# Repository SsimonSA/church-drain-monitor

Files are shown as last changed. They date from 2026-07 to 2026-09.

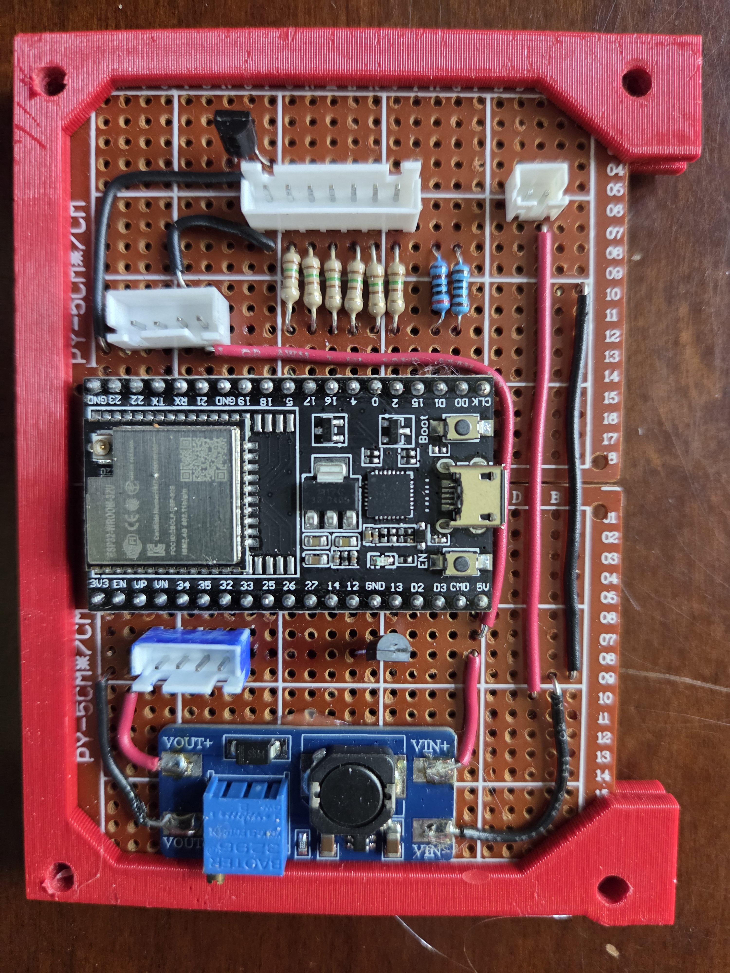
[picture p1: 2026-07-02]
firmware/photos/20-perfboard-component-side.jpg

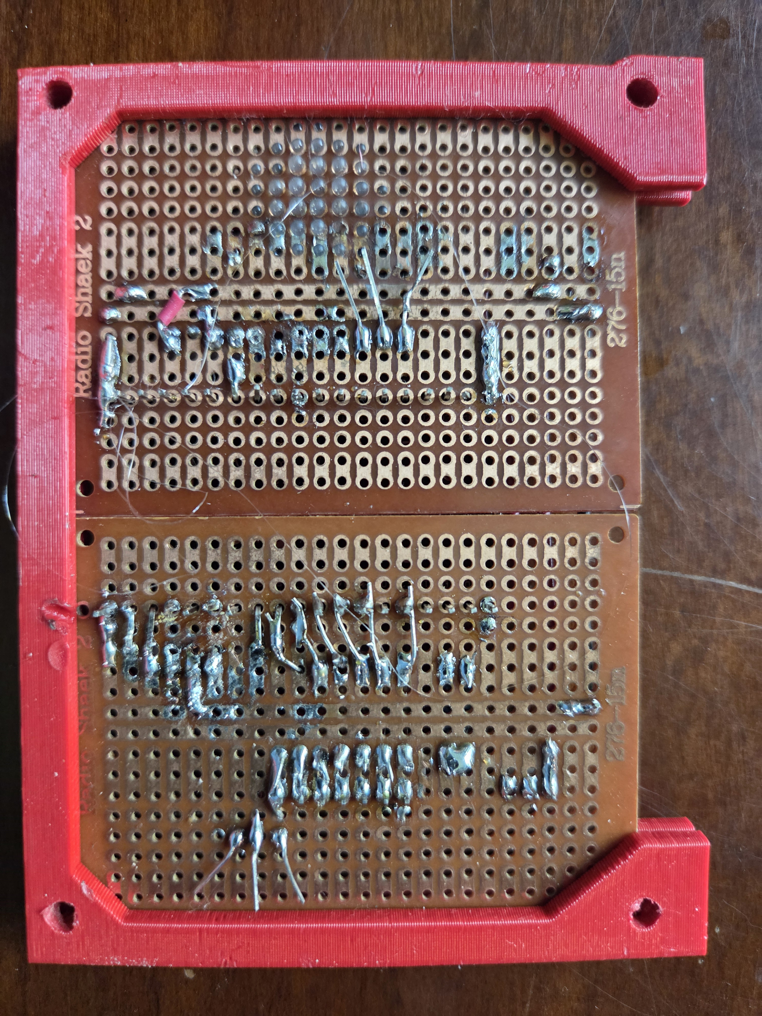
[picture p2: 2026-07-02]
firmware/photos/21-perfboard-solder-side.jpg

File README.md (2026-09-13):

# 🚰 Church Water Drain Monitor

An ESP32-based early-warning system for a church kitchen floor drain that backs up
under a wash sink. A float rides in a 2" PVC standpipe; an HC-SR04 ultrasonic sensor
reads the float height down the bore, driving a 5-LED level bar, a blinking overflow
lamp, and a piezo alarm — and posting depth telemetry to InfluxDB for a Grafana
dashboard. The box is a self-contained alarm first, a cloud sensor second.

See [PROJECT.md](PROJECT.md) for the full design history (sensing approaches tried,
mechanical build, calibration).

## Getting the data off the box

The site has no dependable WiFi, so the firmware assumes it is usually offline and
logs regardless:

- **Store and forward.** Readings go to a persistent log in flash (LittleFS, two
  rotating files, ~37,000 readings ≈ 12 h of continuous 1 Hz logging or ~8 months of
  calm heartbeats). It survives reboots, brownouts and power cuts. When a network
  appears, the backlog is uploaded oldest-first in bounded chunks and back-dated to
  when it was actually measured, so Grafana fills in the past with no dashboard
  changes.
- **Local download.** The device also serves its own history over plain HTTP on the
  LAN — park next to it, turn on a phone hotspot, and open
  **`http://drain.local/log.csv`** (or `http://<ip>/log.csv`; the IP is reported in
  telemetry as the `ip` field). This path needs no InfluxDB, no token, no retention
  window and no internet.

Readings are stamped with **uptime**, not wall-clock, so logging never depends on the
device having had a clock; absolute time is applied on the way out once NTP lands.
Readings taken during a boot that never reached NTP keep their shape in the CSV
(uptime column) but are deliberately **not** sent to InfluxDB — a guessed timestamp
would corrupt the dashboard. A battery-backed RTC (DS3231) would close that gap.

## Repository layout

| Path | What it is |
|---|---|
| `firmware/` | **Field firmware** (`StJoesDrainMonitor`) — the deployed build: sensor, LEDs, buzzer, button, InfluxDB telemetry. |
| `experiments/BenchTest/` | Interactive bench harness — exercise LEDs / buzzer / sensor / WiFi / InfluxDB write from a serial menu. |
| `experiments/BtnLedTest/` | Minimal button + LED sanity sketch. |
| `experiments/vl53l1x-abandoned/` | Abandoned VL53L1X ToF version (kept for reference). |
| `experiments/ultrasonic-original-2025/` | The very first sketch (bare HC-SR04, six LEDs), archived from the old sketchbook. |
| `hardware/3d-models/` | Copies of the printable parts (float, tube liner, sensor cap). |

## Setup — credentials

Credentials are **not** committed. Each firmware project reads them from a gitignored
`secrets.h`. To build:

```sh
cd firmware/src   # (and likewise experiments/BenchTest/src)
cp secrets.example.h secrets.h
# then edit secrets.h with your WiFi network(s) and InfluxDB write token
```

`secrets.h` provides `WIFI_NETS[]`, `N_WIFI`, and `INFLUX_TOKEN`. Use a **write-only,
bucket-scoped** InfluxDB token — that token is embedded in the compiled binary.

## Field visits

The unit is offline except when someone is standing next to it with a phone hotspot, so
an update and its first test happen on the same trip.
**[firmware/docs/field-visit-checklist.md](firmware/docs/field-visit-checklist.md)** is
the pre-flight for that: what to bring, what should happen, what to verify before
leaving, and how to read the serial log if it doesn't.

## Over-the-air updates

The field firmware self-updates over the internet — the device polls a manifest and
flashes a newer binary from a GitHub release when the water is low. There is no push
from the IDE. Full process and the publish/rollback steps are in
[firmware/ota/README.md](firmware/ota/README.md); the live manifest is
[firmware/ota/manifest.txt](firmware/ota/manifest.txt).

## Toolchain

PlatformIO (`espressif32` / `esp32dev`). Open a project folder and `pio run -t upload`.

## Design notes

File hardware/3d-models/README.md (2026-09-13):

# 3D models

Copies of the printable parts, taken from `Dropbox\3D Objects` in September 2026.
Edit the originals there in your slicer; refresh these copies when they change.

| File | Part |
|---|---|
| `Drain Float.3mf` | Float that rides inside the 2" PVC standpipe (2026-07-01) |
| `Drain Tube Liner.3mf` | Liner for the standpipe bore (2026-07-01) |
| `Dist Sensor Cap.3mf` | End cap holding the HC-SR04 at the top of the pipe (2026-06-02) |

The display enclosure and lid were also printed, but the matching files in
`3D Objects` are not named for this project (candidates: `Circuit Board Enclosure`,
`Enclosure Cover`, `Sensor Enclosure`, `Cap V2`). Copy them here once identified.

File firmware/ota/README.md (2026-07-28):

# OTA update process (pull-based)

The deployed firmware ([../src/StJoesDrainMonitor.ino](../src/StJoesDrainMonitor.ino))
updates itself. There is **no push from the IDE** — the device drives everything:

1. Every ~6 h (and ~1 min after boot), if the water level is low and WiFi is up, the
   device fetches [`manifest.txt`](manifest.txt) over HTTPS.
2. It compares the manifest's version to its compiled-in `FW_VERSION`.
3. If the manifest version is **greater**, it downloads the `.bin` at the URL in the
   manifest and flashes it, then reboots into the new image.
4. Equal or lower → no-op. (This is what prevents a reflash loop.)

`manifest.txt` is served straight off the `main` branch via
`raw.githubusercontent.com`, so editing it here **is** publishing.

## Manifest format

Exactly two lines, no JSON:

```
<version integer>
<https URL of the .bin>
```

## Publishing a new firmware version

Do these in order — **bin first, manifest last** — so a device can never fetch a
manifest that points at a `.bin` that isn't uploaded yet.

1. **Bump the version in the source.** Edit `const int FW_VERSION` in
   `../src/StJoesDrainMonitor.ino` to the new number (e.g. `2`).
2. **Build** the release binary:
   ```sh
   cd ..            # into firmware/
   pio run          # output: .pio/build/esp32dev/firmware.bin
   ```
3. **Cut a GitHub release** and attach the binary. The asset's download filename is the
   file's basename and the manifest URL must match it, so **rename the bin before upload**
   — the `path#label` form only sets a display *label*, NOT the download filename:
   ```sh
   cp .pio/build/esp32dev/firmware.bin StJoesDrainMonitor-v2.bin
   gh release create fw-v2 \
     --title "Firmware v2" --notes "what changed" \
     StJoesDrainMonitor-v2.bin
   ```
4. **Flip the manifest** — edit `manifest.txt` to:
   ```
   2
   https://github.com/SsimonSA/church-drain-monitor/releases/download/fw-v2/StJoesDrainMonitor-v2.bin
   ```
   then commit + push to `main`.

Within one check interval each device sees version 2 > its running 1, updates, and
reboots. Confirm success in Grafana: the `fw` field in the `depth` measurement flips
to `2`, and the unit keeps reporting. **To roll back**, point the manifest back at the
older release and its lower version number — but note a device already running the
newer build won't downgrade (its `FW_VERSION` is now higher), so a true rollback
usually means cutting a new release with a *higher* number containing the old code.

## Notes / limitations

- **The reading log lives in the `spiffs` partition, and OTA never touches it.** Only
  the app partition is rewritten, so a firmware update keeps the stored history. Two
  things do wipe it: a change to the partition table (don't), and a change to the
  on-flash record layout. The latter is guarded — `struct Reading` has a
  `static_assert` on its size and the log carries a `LOG_MAGIC` stamp, so a mismatched
  build wipes the log deliberately at boot instead of decoding old bytes as garbage
  depths. **If you change `struct Reading`, bump `LOG_MAGIC`.**
- **First boot of v5 formats that partition** (it was never used before), which adds a
  few seconds to that one boot.

- **Download integrity, not boot-rollback.** The ESP32 verifies the image (size +
  checksum) before switching the boot partition, so a corrupt/truncated *download*
  can't brick the device — the current firmware keeps running. It does **not** auto-
  revert a firmware that flashes cleanly but then crashes at runtime; the Arduino-ESP32
  bootloader isn't built with app-rollback enabled. Test each build on the bench before
  cutting a release.
- **Local post-update self-check (network-independent).** The firmware classifies each
  boot from `esp_reset_reason()` and an NVS crash counter, and logs it over serial:
  `first boot of fw vN`, `clean boot OK`, `CRASH (PANIC/WDT) bad-boot k/3 X`, or a loud
  `SUSPECT BUILD` after 3 firmware crashes. Because it's local, it flags a bad build
  even at a site with no WiFi — you don't have to infer health from dashboard silence.
  **Brownouts are called out separately** as a power fault and never count toward the
  suspect threshold (a flaky supply must not masquerade as a bad binary). The last reset
  reason is also sent as the `rst` telemetry field so Grafana can annotate reboots.
  This surfaces a bad build; it still can't *auto-revert* one (that needs the rollback
  bootloader) — a confirmed-bad unit needs a USB reflash.
- **Safe mode.** Hitting the same 3-crash threshold also disables the subsystems that
  aren't needed to warn anybody: the filesystem and the web server. The sensor, LED
  bar, overflow lamp and buzzer keep running, and telemetry falls back to the RAM
  buffer. It is not a rollback — the unit still needs a USB reflash — but a bad build
  degrades into a working drain alarm instead of a dead box, which matters because
  recovery requires physically visiting the site.
- **TLS is encrypt-only** (`setInsecure()`), matching the telemetry path. Fine for a
  public binary; if you later want MITM protection, pin GitHub's root CA or add a
  SHA-256 check to the manifest.
- **Power first.** Do not rely on OTA until the field unit has the ≥2 A supply + bulk
  cap — a brownout during the flash write is the one thing that *can* brick it.

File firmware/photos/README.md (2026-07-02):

# Project photos

Drop the St. Joes Drain Monitor photos here so future Claude Code sessions can view
them (Claude can open image files on disk with the Read tool, but cannot save images
that were pasted into a chat).

Suggested filenames (match the manifest in the project memory `drain-enclosure.md`):

- `01-enclosure-open.jpg`      — box open: perfboard/ESP32 + lid with 6 LED bezels
- `02-perfboard-closeup.jpg`   — ESP32-WROOM-32U, LED resistors, JST connectors
- `03-front-panel.jpg`         — DRAIN MONITOR / OVERFLOW WARNING + 5-LED level bar
- `04-sr04-in-cap.jpg`         — HC-SR04 in the round 3D-printed sensor cap
- `05-probe-assembly.jpg`      — PVC tube + sensor cap + pencil float + connector
- `06-sr04-cap-closeup.jpg`    — HC-SR04 cap close-up
- `07-esp32-breadboard.jpg`    — ESP32-WROOM-32D on breadboard
- `08-drain-site.jpg`          — the square floor sink / drain
- `09-drain-measured.jpg`      — tape measure across the drain opening (~10-11")
- `10-buzzer-amazon.png`       — the DC 3-24V 95dB active piezo buzzer listing

Any filenames are fine — these just keep them tidy and matched to the notes.

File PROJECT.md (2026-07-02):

# 🚰 Drain Overflow Monitor

Visual early-warning system for a church kitchen floor drain that occasionally backs up
under a wash sink. Goal: warn **before** overflow, in a wet/dirty/greasy environment.

## The problem

- Floor drain begins **overflowing at ~5.5"** of water depth.
- Environment is hostile to sensors: wet, dirty, soap, grease, food residue, scum.
- Need a visual warning that escalates as water rises, flashing before overflow.

### The drain site (photographed)

- Commercial **enameled cast-iron floor sink**, roughly **~12" square opening**, **5.5" deep**,
  with a **dome/flat strainer at the bottom**.
- It's an **indirect-waste receptor**: several vertical PVC pipes plus a horizontal one discharge
  *into* the basin. It backs up when inflow outruns the bottom drain, overflowing at 5.5"
  (flush with the floor).
- The basin is **crowded with existing pipes** — a float standpipe must tuck into a corner,
  rest on the bottom, and have intake holes low so it tracks the basin water level.

## Display (already built)

The enclosure is built and the LED layout is finalized:

- **5 level LEDs:** Green, Green, Yellow, Yellow, Red
- **1 large red LED** that flashes when overflow is imminent

| Water depth | Indication |
|---|---|
| 0" | 1st green LED |
| ~1"  | 2 LEDs |
| ~2"  | 3 LEDs |
| ~3"  | 4 LEDs |
| ~3.5"| 5 LEDs |
| 4" | Large red LED begins flashing |
| 5.5" | Actual overflow begins |

Only need to measure **0"–4"** before warning.

### As-built display unit (photographed)

- 3D-printed two-part enclosure, hex-textured lid: **"DRAIN MONITOR / OVERFLOW WARNING / WATER LEVEL"**, clamp-mounted.
- **ESP32-WROOM-32U** DevKit on a red-framed perfboard.
- 5 bar LEDs (G, G, Y, Y, R) wired through a row of current-limiting resistors; one large **panel-mount red overflow indicator** up top.
- **Toggle power switch** in the box; USB-powered.
- **JST connectors** for the detachable lid-LED harness and for the sensor cable; sensor cable uses an inline waterproof bullet connector.

Current firmware pin map (from the legacy `.ino` — **verify against actual wiring** before reuse):
LGLED=18, HGLED=5, LYLED=17, HYLED=16, LRLED=4, overflow LED=2. (The panel-mount overflow indicator may have a built-in resistor — only ~5 board resistors are visible, matching the 5 bar LEDs.)

## Sensing approach — history

1. **JSN-SR04T ultrasonic** — ❌ Beam spread too wide, drain-wall reflections, splashing, dirt. Unreliable.
2. **VL53L1X ToF (TOF400C modules)** — explored FOV, ROI reduction, Long mode, timing budgets,
   smoothing, auto-calibration. Better than ultrasonic but ❌ still untrustworthy: splashes,
   dirty/changing reflectivity, scum accumulation.
   - *`experiments/vl53l1x-abandoned/ChurchWaterDrainMonito.ino` is this abandoned VL53L1X version.*
3. **Float + Hall sensors** — keeps electronics dry, easy to clean, immune to splashes/optics.
   Designed but **set aside** (see "Alternative / fallback" below) in favor of #4.
4. **Float + HC-SR04 in a pipe (CURRENT direction)** — return to the HC-SR04, but fix its old
   failure modes *mechanically*: a float in a 2" PVC pipe gives the ultrasonic a clean, flat,
   consistent target, and the pipe bore acts as a waveguide that collimates the beam (no more
   drain-wall reflections or splashing). Plays to the SR04's strength at short range. 🔬 Under test.

## Current direction: float + HC-SR04 in a 2" PVC pipe

- **2" PVC pipe** stands vertically in the drain; an **HC-SR04 in a 3D-printed end cap** sits at
  the **top**, aimed down the bore.
- A **3D-printed float** rides on the water surface inside the pipe. The SR04 measures distance to
  the **flat top of the float** → water level = pipe geometry − measured distance.
- The pipe shields the float from splashing/turbulence and collimates the ultrasonic beam.

**Geometry (test rig):** pipe **12" long**, float **~1.5" long**. The float is *closest* to the
sensor at overflow and *farther* as water drops, so:
- At overflow (~5.5" water), sensor-to-float-top ≈ **5"** — comfortably outside the SR04 dead zone.
- The near dead zone (~2 cm, ring-down) is therefore **never reached** in this geometry. The bench
  sweep confirms accuracy/linearity/repeatability over the full travel rather than chasing a dead zone.

### Bench test rig (built, photographed)

- 2" PVC pipe + 3D-printed cap holding the HC-SR04 at one end, on a breadboard ESP32.
- The black float is **hot-glued to a pencil** as a manual actuator: push the float to a known
  position (read off a tape measure at the open end) and compare to the SR04 distance reading.
- Goal: characterize **known float position vs. measured distance** — accuracy, linearity,
  repeatability, and where the near dead zone begins.

## Alternative / fallback: float inside PVC pipe (Hall-sensor version)

- Vertical **1.5" Schedule 40 PVC** pipe; water enters through holes near the bottom.
- A **float** rides up/down inside the pipe with a **magnet** attached.
- **Analog Hall-effect sensors mounted outside the pipe** read the magnet's field.

### Sensors

- Purchased **10x DRV5055A1QLPG** — analog Hall-effect, output proportional to field strength,
  good for interpolation.
- Sensor count strategy evolved: 5 → 3 with interpolation. Current thinking: **3 sensors** may
  suffice for the 0"–4" range, e.g. Sensor 1 = 0", Sensor 2 = 2", Sensor 3 = 4". Magnet field
  overlaps adjacent sensors; interpolate all 3 analog values to estimate float position
  continuously, then map to the LED display.

### Float design

- **38 mm OD × 50 mm long**, pill-shaped, fits inside 1.5" PVC (ID ≈ 41 mm → ~1.5 mm clearance
  per side, tolerant of scum/buildup/print imperfection).
- **Bottom half:** rounded bottom, hollow chamber, magnet pocket.
- **Top half:** M32×2 threaded cap, domed top, tool slot.
- **Thread clearance:** female 32.3 mm / male 31.7 mm (0.6 mm total, 0.3 mm/side) — good FDM start.
- **Magnet:** 10 mm dia × 2.7 mm thick neodymium, in bottom of float, epoxy-sealed. Serves as
  Hall target **and** ballast (keeps float oriented).
- **Buoyancy:** hollow PLA float with a **Styrofoam insert** — stays buoyant even if PLA leaks,
  no perfect seal required.

## Audible alarm (new)

- Adding a **piezo buzzer**: WEICHUANG **SFM-27-W**, DC **3–24 V**, **90 dB**, *active* (self-oscillating,
  continuous tone — just apply DC, no PWM/tone needed). Arriving 2026-05-29.
- **Intended trigger: ~1" below overflow ≈ 4.5" water depth** — between the big-red-LED flashing
  onset (4") and actual overflow (5.5"). Final threshold deferred until the distance experiments
  are done.
- **Drive note:** an active buzzer rated to 24 V can draw more current than an ESP32 GPIO should
  source directly — plan to drive it through a transistor/MOSFET (or confirm draw at 3.3–5 V first).

## Status

**Mechanical:** ✅ enclosure built · ✅ LED layout finalized · ✅ magnet selected · ✅ Hall sensors
ordered · float design underway · threaded cap modeled · 1.5" PVC selected.

**Electronics:** ✅ ESP32 on hand · ✅ DRV5055 sensors purchased. Need: sensor mounting
arrangement, calibration strategy, final interpolation algorithm.

**Software (Hall version):** Not started. Need to: read 3 DRV5055 analog sensors → smooth →
calculate float position → convert to water depth → drive LEDs → flash overflow LED at 4".

## Next major milestone

Build the float, install it in a piece of 1.5" PVC, and **characterize magnetic field vs. height
using one DRV5055 sensor** before committing to final sensor spacing. That experiment determines
how many sensors are actually needed.

The **old ultrasonic test rig** (PVC tube + sensor in a printed end-cap + tape-measure position
reference + breadboard ESP32) is a ready template for this characterization: slide the
magnet/float along the pipe, log DRV5055 analog reading vs. tape-measure position.

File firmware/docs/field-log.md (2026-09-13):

# Field log

Running record of site visits and deployment state. Newest entry at the top.
Add an entry for every visit and every release, even if the outcome is unknown.

## 2026-09-13 — firmware v6 released (flush-before-NTP fix)

- flushChunk() now stops at the first record from the current boot while NTP is still
  pending, so a reboot no longer discards its own backlog from the InfluxDB path.
- Sensing, thresholds and the on-flash record format are unchanged; the stored log
  survives the update.
- Release fw-v6 published and the manifest flipped. Lands on the next visit: stay on the
  hotspot 10+ min, expect the OTA reboot within a minute or two, confirm fw=6 in Grafana.
- Also dropped the unjoinable `SJC Parish Guest` entry from `secrets.h` (5 GHz only) so
  the unit stops burning a 10 s timeout on it each scan cycle. Baked into the v6 binary.
- The readings from 09-01 to 09-13 are still only on the device. Pull `/log.csv` on the
  next visit before the OTA reboot if you want them.

## 2026-09-13 — hotspot drive-by, backlog stops at 09-01

- Hotspot on outside the kitchen. The unit connected and delivered its backlog, but only
  from Sun 08-30 11:45 through Tue 09-01 12:12 EDT (598 readings, hotspot IP 10.73.185.210,
  a different address from the 08-30 flush, so this was today's delivery). Nothing newer
  arrived, and no live readings from today either.
- One real event in that window: Tue 09-01 08:57:22 to 08:57:30, a 9-second excursion
  peaking at 4.82" (raw jumped, slew limiter ramped 1.5, 3.0, 4.5, 4.82, back down).
  Enough to trip the 4.5" fast chirp for a few seconds. Then the 1 Hz settle window and a
  return to calm 10-minute heartbeats until 12:12.
- **Diagnosis (from the firmware, not yet confirmed on the device):** the unit rebooted
  around 12:15 on 09-01 (today's rows carry rst=1, a clean power-on). The new boot had no
  NTP until today. On connect, flushChunk() runs before NTP lands, dates the old session's
  records via the saved anchor, but treats the new session's own pre-NTP records as
  undatable and advances the delivery cursor past them. Seconds later NTP arrives, too late.
  Twelve days of readings are still on flash and are now datable for `/log.csv`, but the
  InfluxDB path has skipped them for good.
- No live point from today because calm mode enqueues only every 10 min and the visit was
  shorter than that.
- **Next visit:** stay on the hotspot 10+ min, download `http://<ip>/log.csv` (the ip field
  shows the address), and read the serial boot line `LOG: mounted — session=N` to confirm
  the session count went up. Ask whether anyone unplugged the box around noon on 09-01.
- **v6 fix:** in flushChunk(), when g_bootEpoch is still 0, stop the chunk at the first
  record from the current session instead of skipping it, so the backlog waits for NTP.

## 2026-09-13 — status check (no visit)

- Reconstructed state from the repo on the desktop laptop. No record of the 2026-08-27
  visit had reached this machine because Claude session data does not sync via Dropbox.
- Added this log and a `CLAUDE.md` so outcomes are written into the repo from now on.
- Moved the project from `Dropbox\Arduino\ChurchWaterDrainMonito` to
  `Dropbox\Sparks Analytics\Projects\ChurchDrainMonitor`, folding in the 2025 sketch and
  the drain 3D models. A signpost README was left at the old path.
- Session history from the other laptop is now shared via Dropbox. The 08-27 through
  08-30 entries below were reconstructed from it.

## 2026-08-30 — hotspot drive-by, backfill confirmed

- Turned on the phone hotspot outside the kitchen. The unit flushed 358 readings covering
  Fri 08-28 00:00 to Sun 08-30 11:35 EDT at exactly 6 per hour, zero gaps.
- Health: fw=5, reset reasons only sw-restart (the OTA) and power-on, no brownout, no panic.
  21 of 21 pings kept on every reading, distance stable within 0.3 cm. Bin dry.
- Established that `SJC Parish Guest` is 5 GHz only. The ESP32 can never join it, so the
  unit is a walk-up logger with no remote alerting until a 2.4 GHz SSID exists.
- Buffer headroom is about 132 days at the calm cadence, so visits are not time-pressured.
- **Open:** ask the parish to enable 2.4 GHz on the AP; drop the dead guest SSID from
  `secrets.h` on the next reflash; rotate the InfluxDB write token; verify depth accuracy
  in the real drain at known fill levels.

## 2026-08-28 — morning after

- The last near-overflow tests from the evening were missing in Grafana. Two causes found:
  the unit was on laptop USB, which browns out the radio while readings keep landing on
  flash, and it was rebooted several times. The firmware keeps only one NTP session anchor,
  so readings from a boot that never reached NTP can never be dated and are skipped on the
  InfluxDB path. They remain in `/log.csv` with the uptime column filled.
- Not a device fault. The single-session anchor is a candidate fix for v6.

## 2026-08-27 — site visit, first v5 install (done)

- On site with the phone hotspot from about 17:52 EDT. Went for the OTA without USB first,
  then attached USB for serial checks.
- v3 to v5 OTA landed. It took about 20 extra minutes: closing and reopening the COM port
  resets the ESP32 and aborts the download, and a failed OTA check waits 6 h before
  retrying (power-cycle to force it).
- First v5 boot printed LittleFS "mount failed", then formatted and remounted. Benign.
- Grafana showed fw=5 and live data. Alarm verified by lifting the float: LED bar, lamp
  and buzzer all worked.
- Power-on session started 18:39 EDT and has run unbroken since.

## 2026-07-28 — firmware v5 released

- Store-and-forward logging to LittleFS, backlog upload to InfluxDB with back-dating,
  on-device `/log.csv`, safe mode after three crashes.
- Manifest flipped to fw-v5. Never run on hardware at release time.
- Server-side items left open: InfluxDB retention on the `drain` bucket, Grafana alert
  rules reacting to backfilled data.

## 2026-07-27 — site visit

- Unit confirmed on v3 with the phone hotspot; the hotspot SSID is in `secrets.h`.

## 2026-07-23 — firmware v3 released

- Re-arm NTP on WiFi reconnect; report SSID in telemetry.

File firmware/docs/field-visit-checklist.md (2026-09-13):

# Field visit checklist — first v5 install

> **Done.** v5 was installed over the air on 2026-08-27 and validated on 2026-08-30. See
> `field-log.md`. This checklist is kept as the template for the next firmware visit.

**State as of 2026-07-28:** firmware **v5 is published and waiting**. The manifest points
at it, the binary is up, but *no device has ever run it*. The field unit is still on
**v3** and will stay there until someone stands next to it with a hotspot.

- Release: https://github.com/SsimonSA/church-drain-monitor/releases/tag/fw-v5
- Commits: `66a1f9e` (firmware), `8ab96ea` (manifest flip)
- Never executed on hardware. It compiles (80.7% flash, 32% RAM) and was reviewed
  closely, but the LittleFS mount, the web server and the session-anchor logic are
  all first-run on this visit.

## Bring

- **Laptop + USB cable.** This is the only rollback. A unit already running v5 has a
  higher `FW_VERSION` than any older release, so it will not downgrade over the air —
  see [../ota/README.md](../ota/README.md).
- A phone with hotspot (the SSID must already be in `secrets.h` — it is, that's how the
  2026-07-27 visit worked).

## What should happen

1. Hotspot on → unit associates, NTP syncs, live data appears in Grafana.
2. **The OTA check trips almost immediately.** Its 6-hour timer has been running dry for
   weeks, so the check fires on the first sample tick after association. Expect a reboot
   within a minute or two — *this is not a crash.*
3. First v5 boot **formats the spiffs partition** (never used before). Adds a few seconds
   to that one boot.
4. It comes up on v5 and starts logging to flash.

The few minutes of v3 data sitting in RAM are lost in that reboot. Expected, not a fault.

## Verify before leaving

- [ ] `http://drain.local/` shows **Firmware v5**. If mDNS won't resolve from the phone,
      use the IP — Grafana now carries it as the `ip` field on the `depth` measurement.
- [ ] That page's **"Log on flash"** figure is growing (it's `log0.bin + log1.bin` bytes).
- [ ] `http://drain.local/log.csv` downloads and opens as a real CSV.
- [ ] Grafana `fw` field flips to `5` and the unit keeps reporting.
- [ ] **Local alarm still works** — this is the part that actually matters. Lift the float
      by hand and confirm the LED bar climbs, the lamp blinks and the buzzer sounds.

## Serial log — what to look at

Every tick prints, among other things:

```
pend=N(flash|RAM)   readings not yet delivered, and where the queue lives
clk=set|unset       whether this boot has an epoch anchor yet
```

Plus at boot: `LOG: mounted — session=N active=… read=… off=…`.

Between them these localize a problem fast:

| Symptom | Reading |
|---|---|
| `pend` climbing, `clk=unset` | Logging fine, no anchor — NTP isn't landing. |
| `pend` climbing, `clk=set`, WiFi up | Delivery failing. Look for the `FLUSH: HTTP …` line — a 4xx here is usually InfluxDB retention, not the network. |
| `pend=0(RAM)` | LittleFS didn't mount; running the RAM fallback. |
| `SAFE MODE` at boot | 3 firmware crashes — filesystem and web server disabled, alarm still running. Needs a USB reflash. |

## If it goes wrong

The unit is designed to fail *toward* being an alarm. In order of severity:

1. **LittleFS won't mount** → falls back to the RAM ring buffer. Telemetry still works,
   history doesn't persist across reboots. Not urgent; drive home.
2. **Crash loop** → after 3 firmware crashes it enters safe mode: no filesystem, no web
   server, sensor/LEDs/lamp/buzzer still running. Confirm the alarm works, then USB
   reflash a known-good build when convenient.
3. **Dead box** → USB reflash on the spot. `pio run -t upload` from `firmware/`.

## Still open (server side, not on the device)

- [ ] **InfluxDB bucket retention on `drain`.** Influx rejects points older than the
      retention window. If it isn't infinite, the first real backlog gets 4xx'd. The
      firmware logs that distinctly but cannot fix it.
- [ ] **Grafana alert rules**, if any exist. Backfilled data is evaluated as it arrives,
      so a backup that ended days ago can fire an alert on delivery.

## Known gap

Readings taken during a boot that *never* reached NTP can't be dated and are never sent
to InfluxDB (they still appear in `/log.csv` with the uptime column filled and epoch
blank). A battery-backed **DS3231** RTC (~$3, I2C) would close this permanently and is
the obvious next hardware addition if it turns out to matter.

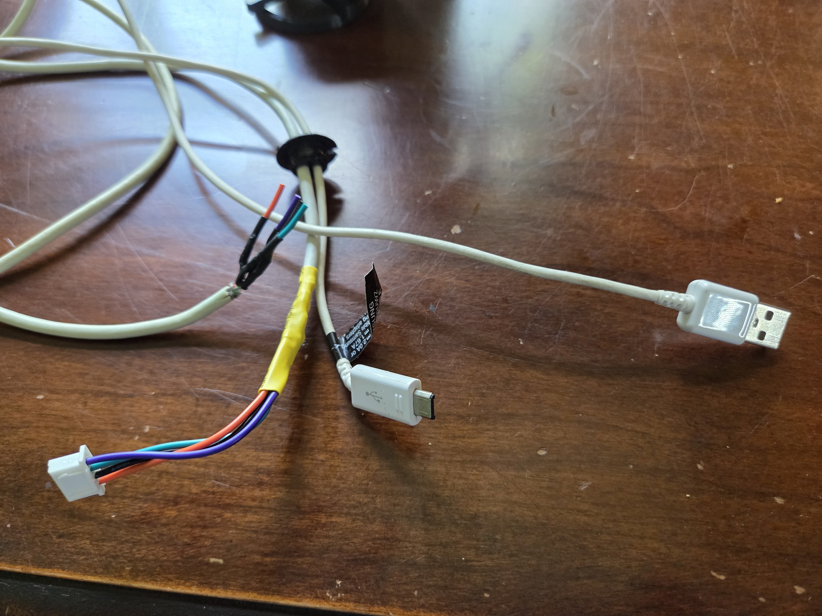
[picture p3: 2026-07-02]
firmware/photos/25-power-sensor-umbilical-cable.jpg

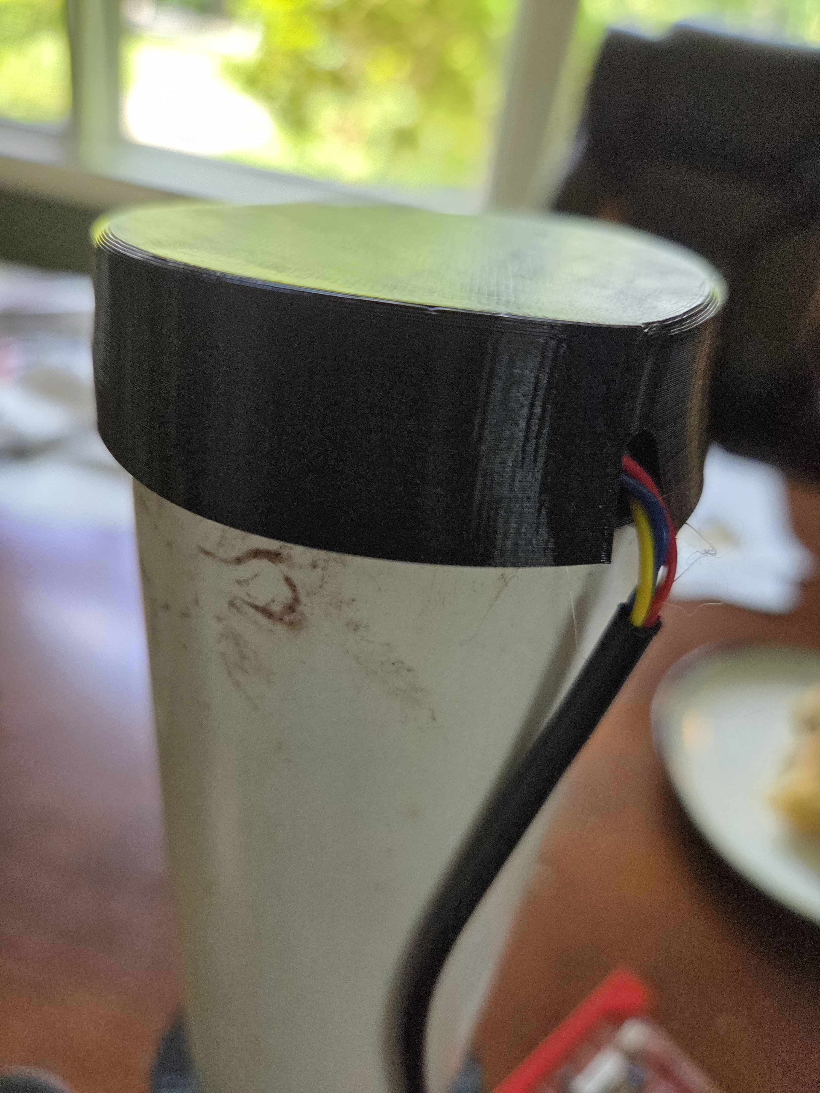
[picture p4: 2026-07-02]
firmware/photos/06-sr04-cap-wires-closeup.jpg

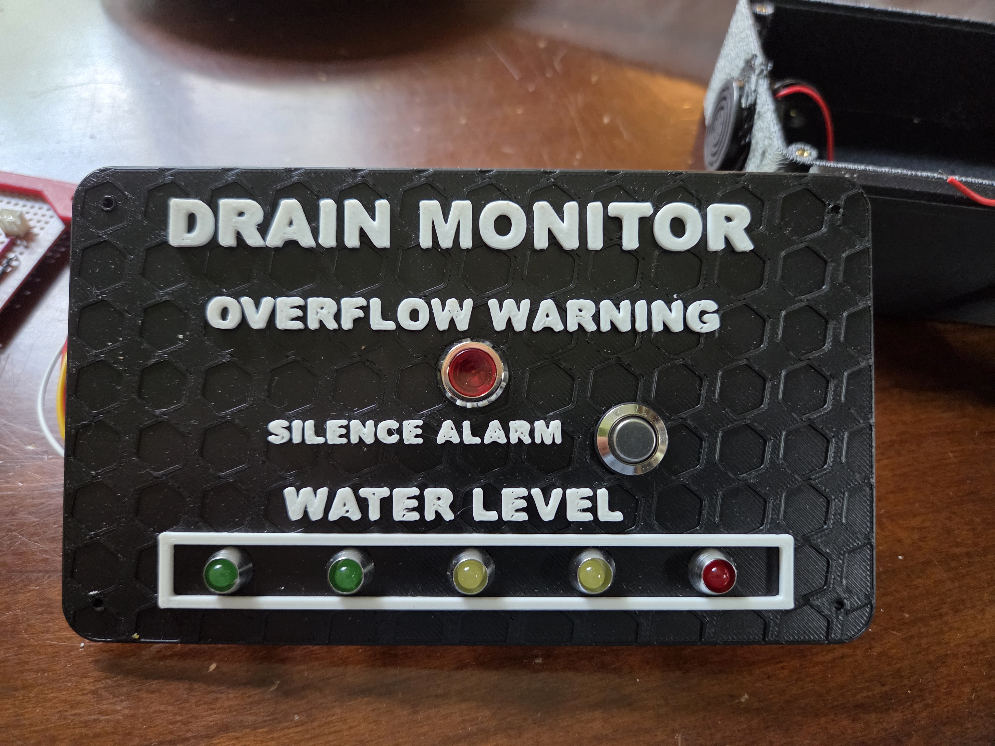
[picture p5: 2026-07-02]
firmware/photos/03-front-panel.jpg

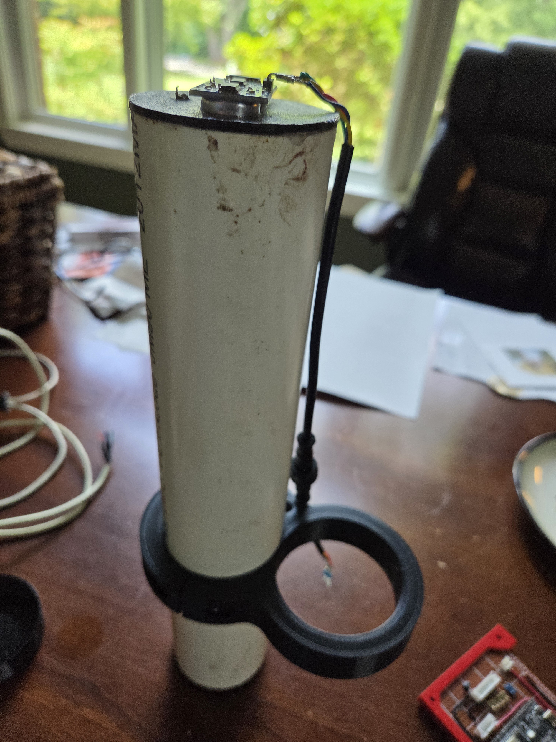
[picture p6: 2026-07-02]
firmware/photos/05-probe-sr04-in-cap.jpg

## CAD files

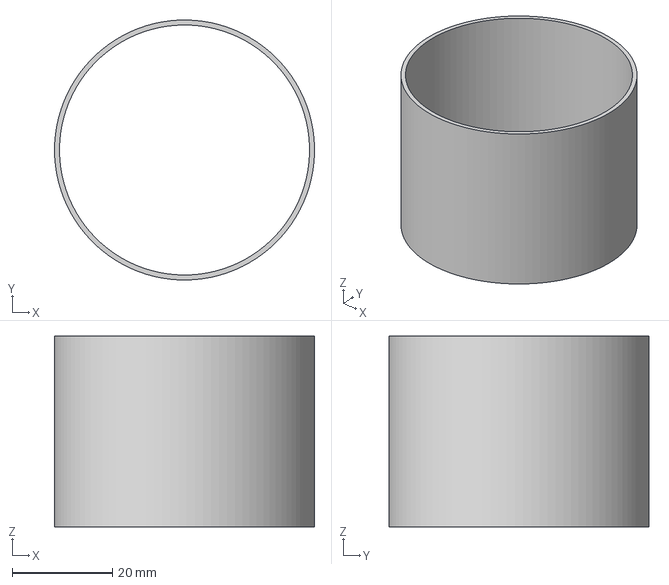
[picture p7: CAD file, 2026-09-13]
hardware/3d-models/Drain Tube Liner.3mf
51.8 x 51.8 x 38.0 mm

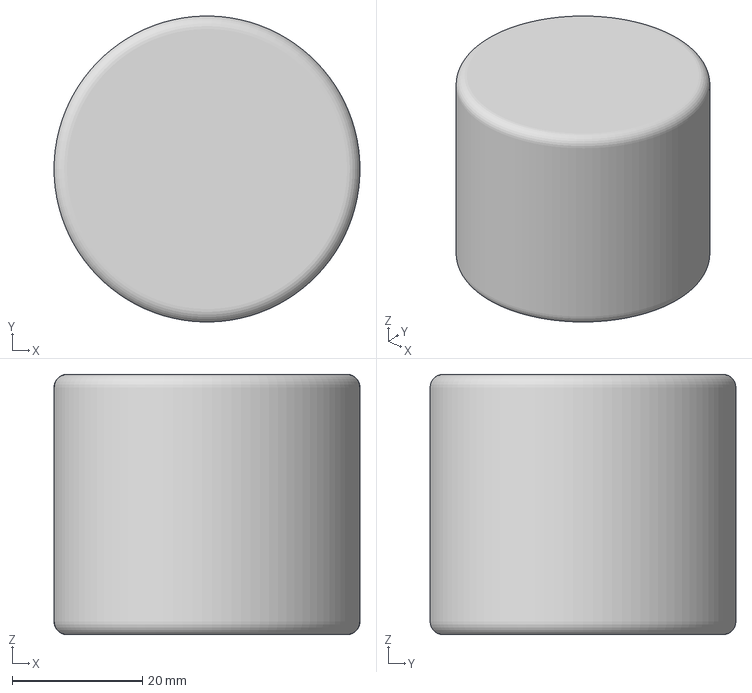
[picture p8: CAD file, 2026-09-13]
hardware/3d-models/Drain Float.3mf
47.0 x 47.0 x 40.0 mm

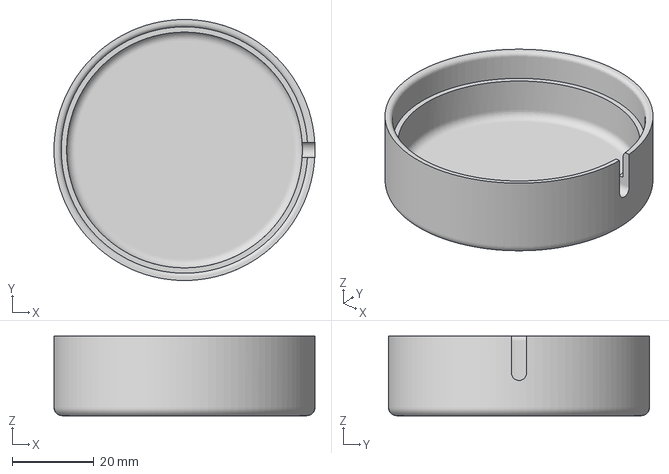
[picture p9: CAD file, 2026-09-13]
hardware/3d-models/Dist Sensor Cap.3mf
64.0 x 64.0 x 19.5 mm

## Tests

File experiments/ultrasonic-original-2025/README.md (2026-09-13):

# Original ultrasonic sketch (July 2025)

`Drain_Warning_System.ino` is the very first version of the drain monitor: a bare
HC-SR04 aimed at the open drain, NewPing, six LEDs on fixed distance thresholds, no WiFi.
It came from the old Arduino IDE sketchbook (`Dropbox\Arduino\Drain_Warning_System`) and
was moved here in September 2026 when the project was consolidated.

History only. Do not flash it and do not treat its pin numbers as current; the deployed
pin map is in `firmware/src/StJoesDrainMonitor.ino`.

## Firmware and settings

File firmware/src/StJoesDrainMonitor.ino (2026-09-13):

/*
 * StJoesDrainMonitor  —  ESP32 + HC-SR04 float-in-pipe water-level monitor
 * ---------------------------------------------------------------------------
 * - SR04 float-in-pipe sensor + two-point calibration -> water depth in inches.
 * - LOCAL indicators (work even if WiFi/cloud is down): 5-LED level bar, a
 *   blinking overflow lamp, and a 95 dB piezo buzzer with TWO audible tiers:
 *   WARN (>=4.0") = short chirp every few seconds (lamp slow-blinks) to prompt the
 *   dishwasher to ease off; ALARM (>=5.0", below the ~5.5" physical overflow) =
 *   full beep-until-acknowledged (lamp fast-blinks). All levels field-tunable.
 * - Momentary pushbutton: SHORT press = acknowledge/silence the current alarm
 *   (lamp keeps blinking); LONG press (~2 s) = master mute toggle (buzzer on/off,
 *   persists across events, re-arms on reboot).
 * - Cloud telemetry: posts depth to InfluxDB (via Caddy/HTTPS) for the Grafana
 *   dashboard, with adaptive cadence + offline store-and-forward.
 *
 * STORE AND FORWARD
 *   Readings are stamped with UPTIME, not wall-clock, so logging never depends on
 *   having had a network. When NTP eventually lands we learn the epoch at uptime 0
 *   and back-date the whole backlog on its way out. A device that powers up out of
 *   range still records everything; it just delivers late. The backlog leaves in
 *   bounded chunks (never one giant POST) and drains flat out only while the water
 *   is low, so a backfill can't stall the alarm.
 *
 *   The queue lives in FLASH (LittleFS, two rotating files ~45k readings total), so
 *   it survives reboots, brownouts and power cuts — RAM holds only a small staging
 *   batch. If the filesystem can't be mounted the firmware falls back to the old
 *   RAM-only ring buffer rather than losing telemetry outright.
 *
 * LOCAL HISTORY DOWNLOAD
 *   The device also serves its own log over plain HTTP on the LAN:
 *     http://drain.local/log.csv   (or http://<ip>/log.csv — the IP is in telemetry)
 *   Park next to the box, turn on a hotspot, open the URL. This path needs no
 *   InfluxDB, no token, no retention window and no internet at all.
 *
 * The LED bar / lamp / buzzer are driven from the ESP32's OWN reading every loop,
 * independent of the network — the box is a self-contained alarm first, a cloud
 * sensor second.
 *
 * TELEMETRY CADENCE
 *   - ACTIVE (level >= 0.5 in): send every second.
 *   - After dropping below 0.5 in, keep sending every second for a 5-min SETTLE
 *     window (recession tail), then CALM = 10-min heartbeat (also a liveness ping).
 *   - Any rise back to >= 0.5 in resumes per-second sending + restarts the timer.
 *
 * ===== GPIO MAP (ESP32-WROOM-32) =====
 *   SR04:    TRIG=22  ECHO=21 (reused old VL53 I2C pins; ECHO via 1k/2k divider; SR04 powered at 5V)
 *   LED bar: LG=18 HG=5 LY=17 HY=16 LR=4   (active-HIGH, climbing with level)
 *   Lamp:    overflow=2   (red, blinks at overflow)
 *   Buzzer:  27  (active piezo via logic-level N-MOSFET low-side switch; on the 12V rail)
 *   Button:  32  (momentary to GND, uses internal pull-up)
 *   Btn LED: 25  (12V ring LED via N-MOSFET low-side switch, active-HIGH:
 *                 solid=armed, off=muted, fast-blink=unacknowledged alarm)
 *   Power:   USB 5V powers the ESP32; ESP32 5V pin -> MT3608 boost (set 12V) -> 12V rail -> buzzer/LED
 */

#include <WiFi.h>
#include <WiFiClientSecure.h>
#include <HTTPClient.h>
#include <HTTPUpdate.h>   // pull-based OTA (device fetches a manifest, self-flashes from a GitHub release)
#include <WebServer.h>    // on-device /log.csv download (grab history without the cloud path)
#include <ESPmDNS.h>      // advertise drain.local so you needn't hunt for a DHCP address
#include <LittleFS.h>     // persistent reading log — survives reboot, brownout, power loss
#include <Preferences.h>  // NVS-backed boot/version state for the post-update self-check
#include <esp_system.h>   // esp_reset_reason()
#include <time.h>

#include "secrets.h"   // WIFI_NETS[], N_WIFI, INFLUX_TOKEN — gitignored; see secrets.example.h

// ====== WIFI (networks + priority order live in secrets.h; falls through on failure, then cycles) ======
const unsigned long WIFI_ATTEMPT_MS = 10000UL; // per-network connect timeout

// ====== NTP ======
// The clock no longer gates LOGGING (readings carry uptime and are back-dated at flush
// time — see g_bootEpoch), but it still gates DELIVERY, since InfluxDB needs absolute
// timestamps. The boot-time sync attempt fails whenever the device powers up out of WiFi
// range, and ESP-IDF's background SNTP client only retries about hourly. serviceNtp()
// re-arms on every down->up WiFi transition so a device that has been offline can ship
// its backlog within seconds of a network appearing.
const time_t        NTP_VALID_EPOCH = 1700000000; // any time_t above this is a real clock
const unsigned long NTP_REARM_MS    = 60000UL;    // while online but unsynced, retry this often

// ====== INFLUXDB (via Caddy HTTPS reverse proxy) ======
const char* INFLUX_WRITE_URL =
    "https://stjoesdrain.eastus.cloudapp.azure.com/api/v2/write?org=stjoes&bucket=drain&precision=s";
// INFLUX_TOKEN is provided by secrets.h (gitignored)
const char* DEVICE_TAG = "drain-1";
// TLS: encrypt but skip cert validation (setInsecure); the write token is the gate.

// ====== OTA (pull-based) ======
// The device periodically fetches a plain-text manifest and, if it advertises a
// version newer than FW_VERSION, downloads that .bin and self-flashes. There is NO
// push path — updates are driven entirely by the device. Publishing an update =
// upload the new .bin as a GitHub release asset, then bump the manifest (see
// firmware/ota/README.md). Never flashes while the water is high (see loop()).
//
// >>> BUMP FW_VERSION ON EVERY RELEASE. The manifest's version must EXCEED this to
//     trigger an update; equal or lower is a no-op, which is what stops reflash loops.
const int FW_VERSION = 6;
const char* OTA_MANIFEST_URL =
    "https://raw.githubusercontent.com/SsimonSA/church-drain-monitor/main/firmware/ota/manifest.txt";
const unsigned long OTA_CHECK_INTERVAL_MS = 6UL * 3600UL * 1000UL;  // re-check every 6 h
const unsigned long OTA_FIRST_CHECK_MS    = 60000UL;               // first check ~1 min after boot
                                                                   // (long enough to send startup telemetry first)

// Post-update self-check: prove a new binary is healthy LOCALLY (no network needed).
const unsigned long VALIDATE_STABLE_MS = 60000UL;  // run this long without a crash -> mark the firmware good
const int OTA_BAD_BOOT_LIMIT = 3;                  // this many firmware-CRASH reboots since an update -> loud SUSPECT warning
                                                   // AND safe mode (see g_safeMode)

// ====== SENSOR (HC-SR04) ======
const int   TRIG_PIN = 22;   // reused from old VL53 I2C (SCL); direct 3.3V drive OK
const int   ECHO_PIN = 21;   // reused from old VL53 I2C (SDA); SR04 5V echo -> via 1k/2k divider
const int   SAMPLES          = 21;       // pings per reading (odd -> clean median)
const unsigned long ECHO_TIMEOUT_US = 30000UL;
const int   PING_GAP_MS      = 8;        // between pings (short; we service alarm/button in the gap)
const float US_PER_CM = 58.0f;

// ====== CALIBRATION — direct linear fit: level(in) = CAL_SLOPE*raw_cm + CAL_INTERCEPT ======
// Least-squares fit from real-water test 2026-07-01 (ultrasonic-tank, lined 2" PVC, new float):
//   raw 23.6cm=1"  21.4=2"  19.0=3"  17.5=4"  14.45=5"   (1/2/3/5 collinear; 4" slightly noisy)
// Below DEADBAND_IN the float rests on the base (nonlinear/fuzzy) -> report exactly 0.
// To recalibrate: refit these two numbers from fresh (raw_cm, inches) pairs.
const float CAL_SLOPE     = -0.4468f;   // inches per cm (raw shrinks as water rises)
const float CAL_INTERCEPT = 11.57f;     // inches at raw_cm = 0
const float DEADBAND_IN   = 1.4f;       // empty -> clamp to 0.00. Generous: float rest wanders up to ~1.0",
                                        // so 1.4 keeps the 2nd green dark at empty (HG then lights at ~1.4" real).

// ====== ROBUSTNESS (validated on the bench) ======
// #1 PLAUSIBILITY GATE — the float echo must land in this one-way distance band;
//    anything nearer (wall/rim/cross-talk) or farther (no float) is dropped BEFORE
//    the median, so a spurious short echo can't pull the reading down. Generous for
//    now (tube is 30.7 cm); tighten to the real travel band once field-verified.
const float DIST_MIN_CM = 7.0f;    // lowered from 10: at ~5.5" overflow raw drops to ~9.9 cm; 10 would clip it
const float DIST_MAX_CM = 30.0f;
// #3 SLEW LIMIT — real water can't move this many inches between 1 s samples, so a
//    bigger jump is clamped. One stray sample can't spike the level or trip an alarm.
const float MAX_SLEW_IN = 1.5f;

// ====== LOCAL INDICATORS ======
#define PIN_LED_LG 18   // green  (lowest bar segment)
#define PIN_LED_HG 5    // green
#define PIN_LED_LY 17   // yellow
#define PIN_LED_HY 16   // yellow
#define PIN_LED_LR 4    // red    (highest bar segment)
#define PIN_LAMP   2    // overflow lamp (blinks)
#define PIN_BUZZER 27   // active piezo (via logic-level N-MOSFET from the 12V rail)
#define PIN_BUTTON 32   // momentary, to GND, INPUT_PULLUP
#define PIN_BTN_LED 25  // 12V ring LED (status) via N-MOSFET from 12V rail, active-HIGH

// Bar climbs with depth; lowest green is an always-on "alive/powered" indicator.
const float BAR_HG_IN = 1.0f;
const float BAR_LY_IN = 2.0f;
const float BAR_HY_IN = 3.0f;
const float BAR_LR_IN = 4.0f;
// Two audible tiers so the dishwasher gets time to shut the faucet before overflow.
// (Physical overflow is ~5.5"; the urgent alarm trips BELOW that for reaction time.)
// All field-tunable.
const float WARN_IN        = 4.0f;   // pre-overflow tier 1: slow chirp
const float WARN2_IN       = 4.5f;   // pre-overflow tier 2: faster chirp (escalating)
const float ALARM_IN       = 5.0f;   // urgent: full beep-until-acknowledged
const float ALARM_CLEAR_IN = 4.8f;   // hysteresis: re-arm the ack below this

// Overflow lamp runs on the ESP32 LEDC (hardware PWM), so its blink is timer-generated and
// stays perfectly even even while the loop is busy (network upload / ping burst block it).
#define LAMP_LEDC_CH   4                     // an otherwise-unused LEDC channel
const int      LAMP_LEDC_BITS = 20;          // 20-bit resolution -> supports ~0.07..76 Hz
const uint32_t LAMP_LEDC_DUTY = 1UL << 19;   // 50% duty = symmetric square-wave blink
const float LAMP_HZ_ALARM = 5.0f;            // ALARM: 5 Hz strobe
const float LAMP_HZ_WARN2 = 1.67f;           // WARN2: faster blink (~300 ms period)
const float LAMP_HZ_WARN  = 0.71f;           // WARN:  slow blink (~700 ms period)
const unsigned long BTN_LED_BLINK_MS = 150UL;// button lamp fast-blink = unacked alarm
const unsigned long BEEP_MS       = 350UL;   // ALARM buzzer beep on/off period
const unsigned long WARN_CHIRP_GAP_MS  = 3500UL; // silence between WARN (tier 1) chirps
const unsigned long WARN2_CHIRP_GAP_MS = 1200UL; // silence between WARN2 (tier 2) chirps — faster
const unsigned long WARN_CHIRP_LEN_MS  = 60UL;   // length of each warn chirp (both tiers)
const unsigned long LONG_PRESS_MS = 2000UL;  // hold this long = master mute toggle
const unsigned long DEBOUNCE_MS   = 30UL;

// ====== TELEMETRY POLICY ======
const unsigned long SAMPLE_INTERVAL_MS = 1000UL;   // read + active-send cadence
const unsigned long SETTLE_MS          = 300000UL; // 5 min fast after dropping below threshold
const unsigned long SLOW_INTERVAL_MS   = 600000UL; // 10 min heartbeat once calm
const unsigned long WATCHDOG_MS        = 1800000UL;
const float TELEMETRY_THRESHOLD = 0.5f;            // active/calm boundary for sending

// ====== buffered readings ======
// A reading is timestamped one of two ways, distinguished by RD_RESOLVED:
//   resolved   -> `t` is a real epoch, settled for good
//   unresolved -> `t` is seconds since the boot of session `sess`
// Uptime alone was enough while the queue lived in RAM, but the flash log now OUTLIVES
// reboots, and uptime restarts at zero on each one. Anchoring an old record to the current
// boot's epoch would scatter history across the wrong days — worse than not sending it —
// so every record carries the session it was measured in and is only ever dated against
// that session's own anchor. See resolveEpoch().
const uint16_t RD_RESOLVED = 0x0001;
struct Reading {
  uint32_t t;                                        // epoch if resolved, else uptime seconds
  float in; float rawCm;
  int16_t rssi; int16_t kept; int16_t outWin; int16_t noEcho;
  uint16_t sess;                                     // boot session that measured this
  uint16_t flags;
};
// The on-flash log stores these verbatim, so the size is part of the file format: a change
// here silently misreads every older record. Bump LOG_MAGIC below if this struct changes.
static_assert(sizeof(Reading) == 24, "Reading size is the on-flash record size — bump LOG_MAGIC if you change it");

// RAM staging. With the filesystem up this is just a write-behind batch on its way to
// flash; if the mount failed it degrades into the old standalone ring buffer.
const int BUF_MAX = 2000;
Reading rbuf[BUF_MAX];
int rcount = 0;

// Backlog leaves in bounded batches: ~200 points is ~30 KB of line protocol, which the
// heap can hold comfortably. One giant POST of a full buffer would both blow memory and
// freeze the alarm for the length of the upload.
const int FLUSH_CHUNK = 200;

// ====== persistent log (LittleFS) ======
// Two files used as a coarse ring: we always append to the ACTIVE one and, when it fills,
// delete the other (the older generation) and start writing there. Coarse rotation rather
// than a true record-level ring because deleting from the front of a file isn't a thing —
// the cost is that the backlog drops in ~448 KB steps rather than one reading at a time.
//
// Sizing: the `spiffs` partition in default.csv is ~1.4 MB; 2 x 448 KB leaves LittleFS
// plenty of free blocks (it degrades badly near full) and holds ~45,000 readings — about
// 12 h of continuous 1 Hz logging during a backup, or ~10 months of calm heartbeats.
const char*  LOG_PATH[2]    = { "/log0.bin", "/log1.bin" };
const size_t LOG_FILE_MAX   = 448UL * 1024UL;
const size_t LOG_RECSZ      = sizeof(Reading);
const uint32_t LOG_MAGIC    = 0x44524E32UL;   // 'DRN2' — record-format version guard
// Write-behind policy: batch records so a flash page isn't burned per reading, but never
// hold data in volatile RAM for long — the whole point is surviving an unannounced power cut.
const int           LOG_COMMIT_N  = 32;
const unsigned long LOG_COMMIT_MS = 60000UL;

bool     g_fsOk    = false;   // false -> RAM-only fallback (see rbuf)
uint8_t  g_logAct  = 0;       // file we append to
uint8_t  g_logRd   = 0;       // file we are delivering from
uint32_t g_logOff  = 0;       // byte offset of the next undelivered record in g_logRd
uint16_t g_sess    = 0;       // this boot's session id (NVS counter, increments every boot)
// The most recent PREVIOUS session that managed to learn an epoch anchor. Records committed
// early in that session — before its own NTP sync landed — are still sitting unresolved in
// the log, and this is what lets a later boot date them instead of discarding them.
uint16_t g_anchSess  = 0;
uint32_t g_anchEpoch = 0;
Preferences logPrefs;
unsigned long lastCommitMs = 0;
// Undelivered-record count, refreshed once per sample tick and decremented as chunks land.
// Cached because the true count needs a filesystem stat, and the burst-drain test below
// runs every loop iteration (~200 Hz) — statting flash that often would be absurd.
uint32_t g_pending = 0;

// ====== diagnostics from the most recent reading (raw distance + ping quality) ======
float g_rawCm  = NAN;   // median of the in-window pings, in cm (pre-calibration distance)
int   g_kept   = 0;     // pings that landed inside the plausibility window
int   g_outWin = 0;     // pings with an echo but outside the window (gate-rejected)
int   g_noEcho = 0;     // pings with no echo at all

// ====== uptime / absolute-time anchor ======
// Epoch corresponding to uptime 0, or 0 while still unknown. Learned once, the first time
// NTP produces a real clock: bootEpoch = now - uptime. Every buffered reading then becomes
// absolute (bootEpoch + up) — including the ones recorded hours earlier with no clock at
// all. This is the whole trick behind offline logging.
//
// It survives a soft reboot for free: ESP.restart() and the OTA reboot keep the RTC domain
// powered, so time() is already valid in setup() and the anchor is re-established on the
// first serviceNtp() call. Only a true power cycle loses it — and readings taken during a
// powered-down-then-offline stretch genuinely have no recoverable absolute time. A
// battery-backed RTC (DS3231) would close that last gap if the site ever needs it.
uint32_t g_bootEpoch = 0;
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
void loop() {
  unsigned long ms = millis();
  serviceFast();       // alarm/button/LEDs responsive at loop rate
  if (!g_safeMode) server.handleClient();   // /log.csv download — cheap when nobody is connected

  if (ms - lastSampleMs >= SAMPLE_INTERVAL_MS) {
    lastSampleMs = ms;
    ensureWifi();
    serviceNtp();              // re-arm the clock on reconnect — without it, delivery stays gated off
    if (!g_safeMode) serviceMdns();   // (re)advertise drain.local after any reassociation
    serviceLogCommit();        // never leave a staged batch in RAM longer than LOG_COMMIT_MS
    markValidatedIfStable();   // once we've run stably, mark this firmware good (network-independent)

    float lvl = readLevelInches();
    if (!isnan(lvl)) {
      static bool haveLast = false;           // #3 slew limit: clamp jumps vs the last accepted level
      if (haveLast) {
        float dz = lvl - lastLevelIn;
        if (dz >  MAX_SLEW_IN)      lvl = lastLevelIn + MAX_SLEW_IN;
        else if (dz < -MAX_SLEW_IN) lvl = lastLevelIn - MAX_SLEW_IN;
      }
      haveLast = true;
      lastLevelIn = lvl;                       // accepted (slew-limited) value drives indicators AND telemetry
    }

    // ----- telemetry cadence (settle window then 10-min calm) -----
    bool doEnqueue = false;
    const char* regime = "no-echo";
    if (!isnan(lvl)) {
      if (lvl >= TELEMETRY_THRESHOLD) {
        regime = isBelow ? "RISE" : "active";
        isBelow = false;
        doEnqueue = true;
      } else {
        if (!isBelow) { isBelow = true; belowSinceMs = ms; }
        if (ms - belowSinceMs < SETTLE_MS) { regime = "settling"; doEnqueue = true; }
        else { regime = "calm"; if (ms - lastEnqueueMs >= SLOW_INTERVAL_MS) doEnqueue = true; }
      }
    }
    // No clock check here — that gate is exactly what left an offline box with nothing to
    // send. Buffer unconditionally; absolute time is applied later, at flush.
    if (doEnqueue) {
      enqueue(uptimeSec(), lvl, g_rawCm, (int16_t)WiFi.RSSI(),
              (int16_t)g_kept, (int16_t)g_outWin, (int16_t)g_noEcho);
      lastEnqueueMs = ms;
    }

    g_pending = logPendingRecords();     // authoritative refresh, once per second
    uint32_t pending = g_pending;
    Serial.printf("level=%s in  raw=%s cm  [k=%d ow=%d ne=%d]  regime=%s  pend=%lu(%s)  wifi=%s  clk=%s  buz=%d mute=%d ack=%d\n",
                  isnan(lvl) ? "NaN" : String(lvl, 2).c_str(),
                  isnan(g_rawCm) ? "NaN" : String(g_rawCm, 2).c_str(),
                  g_kept, g_outWin, g_noEcho, regime,
                  (unsigned long)pending, g_fsOk ? "flash" : "RAM",
                  WiFi.status() == WL_CONNECTED ? "up" : "down",
                  g_bootEpoch ? "set" : "unset",
                  (int)beepOn, (int)muted, (int)acked);

    // Steady state: one chunk per tick keeps up easily (we only produce 1 reading/s).
    // A real backlog is drained by the burst path at the bottom of loop().
    if (WiFi.status() == WL_CONNECTED && pending > 0) { if (flushChunk()) lastSendOkMs = ms; }

    // ----- OTA check: infrequent, ONLY when online AND the water is low (never mid-warn/alarm) -----
    // Gating on lastLevelIn < WARN_IN means a reboot-for-update can't take the alarm offline
    // during an actual backup. checkForOTA() blocks a few seconds and reboots on success.
    if (WiFi.status() == WL_CONNECTED &&
        lastLevelIn < WARN_IN &&
        ms - lastOtaCheckMs >= OTA_CHECK_INTERVAL_MS) {
      lastOtaCheckMs = ms;
      logCommit();     // a successful update reboots without returning — don't lose staged readings
      checkForOTA();
    }

    // ----- watchdog: "associated but not delivering", NOT "no network" -----
    // Previously this rebooted after WATCHDOG_MS without a successful send, which at a
    // site whose WiFi is usually absent meant a reboot every 30 minutes — each one wiping
    // the very backlog store-and-forward exists to preserve. Hold the timer open unless
    // we are actually connected AND have something to deliver; then a stalled TLS/HTTP
    // stack is still caught, but simply being out of range is not a fault.
    if (WiFi.status() != WL_CONNECTED || pending == 0) lastSendOkMs = ms;
    if (ms - lastSendOkMs > WATCHDOG_MS) {
      Serial.println("Watchdog reboot");
      logCommit();     // the log outlives the reboot; the staging batch would not
      delay(200);
      ESP.restart();
    }
  }

  // ----- backlog burst drain -----
  // Only while the water is low, mirroring the OTA gate: back-to-back uploads block the
  // loop for their duration, so a backfill is never allowed to compete with an active
  // alarm. serviceFast() at the top of loop() runs between chunks either way.
  if (WiFi.status() == WL_CONNECTED && lastLevelIn < WARN_IN &&
      g_pending > (uint32_t)FLUSH_CHUNK) {
    if (flushChunk()) lastSendOkMs = millis();
    else g_pending = 0;   // stale estimate or a failing send — stop bursting until the next tick
  }

  delay(5);
}

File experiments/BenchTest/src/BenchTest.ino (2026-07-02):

/*
 * Interactive bench-test menu — St. Joes Drain Monitor bring-up
 * ---------------------------------------------------------------------------
 * Exercises each subsystem ONE keypress at a time so a fault is isolated to a
 * single component. Type the menu key in the serial monitor (no Enter needed —
 * `pio device monitor` sends keystrokes immediately).
 *
 * Pin map + calibration copied verbatim from the main firmware so this tests
 * the REAL wiring, not a guess.
 *
 *   1  LED bar walk      — light each of the 5 segments in turn (GPIO 18/5/17/16/4)
 *   2  LED bar all-on    — all 5 segments on for 2 s
 *   o  Overflow lamp     — blink the red lamp 5x (GPIO 2)
 *   b  Button watch      — print press / short / long-press events (GPIO 32); 'x' exits
 *   r  Ring LED toggle   — flip the button's ring LED on/off (GPIO 25 -> MOSFET)
 *   z  Buzzer blip       — one short beep (GPIO 27 -> MOSFET)  ** LOUD: 95 dB **
 *   s  Sensor read       — continuous SR04 raw cm + calibrated inches; 'x' exits
 *   w  WiFi join         — try the 3 networks in order, print IP/RSSI
 *   t  Cloud write       — one test point to InfluxDB (needs WiFi up first)
 *   h  Help              — reprint this menu
 */

#include <WiFi.h>
#include <WiFiClientSecure.h>
#include <HTTPClient.h>

#include "secrets.h"   // WIFI_NETS[], N_WIFI, INFLUX_TOKEN — gitignored; see secrets.example.h
#include <time.h>

// ===== GPIO MAP (matches main firmware) =====
#define PIN_LED_LG 18   // green  (lowest bar segment)
#define PIN_LED_HG 5    // green
#define PIN_LED_LY 17   // yellow
#define PIN_LED_HY 16   // yellow
#define PIN_LED_LR 4    // red    (highest bar segment)
#define PIN_LAMP   2    // overflow lamp
#define PIN_BUZZER 27   // active piezo via N-MOSFET on the 12V rail
#define PIN_BUTTON 32   // momentary, to GND, INPUT_PULLUP
#define PIN_BTN_LED 25  // ring LED via N-MOSFET on the 12V rail, active-HIGH

const int TRIG_PIN = 22;
const int ECHO_PIN = 21;

// ===== SR04 + calibration (from main firmware) =====
const int   SAMPLES = 21;
const unsigned long ECHO_TIMEOUT_US = 30000UL;
const int   PING_GAP_MS = 8;
const float US_PER_CM = 58.0f;
const float TUBE_LEN_CM  = 30.7f;
const float FLOAT_LEN_CM = 4.0f;
const float CM_PER_IN    = 2.54f;
const float CAL_RAW_LO   = 0.43f;
const float CAL_TRUE_LO  = 0.00f;
const float CAL_RAW_HI   = 4.909f;
const float CAL_TRUE_HI  = 5.00f;
const float ZERO_OFFSET_IN = 1.27f;   // 0.42 -> 0.84 (tube shortened) -> 1.27 (+0.43, re-zero for new float/press-fit cap)

// ===== WiFi / InfluxDB (WIFI_NETS[], N_WIFI, INFLUX_TOKEN come from secrets.h) =====
const unsigned long WIFI_ATTEMPT_MS = 10000UL;
const char* INFLUX_WRITE_URL =
    "https://stjoesdrain.eastus.cloudapp.azure.com/api/v2/write?org=stjoes&bucket=drain&precision=s";
const char* DEVICE_TAG = "drain-1";

const int LED_PINS[5] = { PIN_LED_LG, PIN_LED_HG, PIN_LED_LY, PIN_LED_HY, PIN_LED_LR };
const char* LED_NAMES[5] = { "LG green", "HG green", "LY yellow", "HY yellow", "LR red" };

// Defined up here (before any function) so the auto-generated .ino prototypes
// that return it are valid.
struct SensorRead {
  float medianCm;   // median of the IN-WINDOW pings, or -1 if none survived
  float inches;     // calibrated level for that median, or NAN
  int   kept;       // pings inside the plausibility window
  int   outWin;     // pings with an echo but outside the window (rejected by #1)
  int   noEcho;     // pings with no echo at all
};

// ---------- helpers ----------
void allLedsOff() {
  for (int i = 0; i < 5; i++) digitalWrite(LED_PINS[i], LOW);
}

// true if the user pressed a key (used to break out of continuous modes)
bool keyPressed() { return Serial.available() > 0; }

float pingOnce() {
  digitalWrite(TRIG_PIN, LOW);  delayMicroseconds(3);
  digitalWrite(TRIG_PIN, HIGH); delayMicroseconds(10);
  digitalWrite(TRIG_PIN, LOW);
  unsigned long us = pulseIn(ECHO_PIN, HIGH, ECHO_TIMEOUT_US);
  if (us == 0) return -1.0f;
  return us / US_PER_CM;
}

void sortAsc(float *a, int n) {
  for (int i = 1; i < n; i++) {
    float key = a[i]; int j = i - 1;
    while (j >= 0 && a[j] > key) { a[j + 1] = a[j]; j--; }
    a[j + 1] = key;
  }
}

// ===== ROBUSTNESS TUNING (bench) =====
// #1 PLAUSIBILITY GATE — the float echo must land inside this one-way distance
//    band. Anything NEARER (wall / rim / cross-talk) or FARTHER (no float) is
//    discarded BEFORE the median, so a spurious 4 cm echo can't pull the reading
//    short. These are deliberately generous for now (tube is 30.7 cm long); they
//    get tightened to the real float-travel band at calibration.
const float DIST_MIN_CM = 10.0f;
const float DIST_MAX_CM = 30.0f;
// #3 SLEW LIMIT — real water can't jump this many inches between samples, so a
//    larger jump is clamped to this step. One stray sample can't spike the level.
const float MAX_SLEW_IN = 1.5f;

float cmToInches(float median) {
  float rawIn = (TUBE_LEN_CM - (median + FLOAT_LEN_CM)) / CM_PER_IN;
  float slope = (CAL_TRUE_HI - CAL_TRUE_LO) / (CAL_RAW_HI - CAL_RAW_LO);
  float levelIn = CAL_TRUE_LO + (rawIn - CAL_RAW_LO) * slope - ZERO_OFFSET_IN;
  if (levelIn < 0.0f) levelIn = 0.0f;
  return levelIn;
}

// Burst of SAMPLES pings, keeping only echoes inside the plausibility window (#1),
// then median those. Reports the kept/out-of-window/no-echo breakdown so you can
// SEE the gate rejecting junk live.
SensorRead readSensorGated() {
  static float buf[SAMPLES];
  int kept = 0, outWin = 0, noEcho = 0;
  for (int i = 0; i < SAMPLES; i++) {
    float d = pingOnce();
    if (d <= 0)                                  noEcho++;
    else if (d < DIST_MIN_CM || d > DIST_MAX_CM) outWin++;     // #1 reject
    else                                         buf[kept++] = d;
    delay(PING_GAP_MS);
  }
  SensorRead r;
  r.kept = kept; r.outWin = outWin; r.noEcho = noEcho;
  if (kept == 0) { r.medianCm = -1.0f; r.inches = NAN; return r; }
  sortAsc(buf, kept);
  r.medianCm = buf[kept / 2];
  r.inches   = cmToInches(r.medianCm);
  return r;
}

// ---------- tests ----------
void testLedWalk() {
  Serial.println(F("[1] LED bar walk — each segment 600 ms"));
  allLedsOff();
  for (int i = 0; i < 5; i++) {
    Serial.printf("    seg %d: %s (GPIO %d)\n", i + 1, LED_NAMES[i], LED_PINS[i]);
    digitalWrite(LED_PINS[i], HIGH);
    delay(600);
    digitalWrite(LED_PINS[i], LOW);
  }
  Serial.println(F("    done."));
}

void testLedAll() {
  Serial.println(F("[2] LED bar all-on for 2 s"));
  for (int i = 0; i < 5; i++) digitalWrite(LED_PINS[i], HIGH);
  delay(2000);
  allLedsOff();
  Serial.println(F("    done."));
}

void testLamp() {
  Serial.println(F("[o] Overflow lamp — 5 blinks"));
  for (int i = 0; i < 5; i++) {
    digitalWrite(PIN_LAMP, HIGH); delay(300);
    digitalWrite(PIN_LAMP, LOW);  delay(300);
  }
  Serial.println(F("    done."));
}
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

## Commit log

2026-07-02 Initial commit: ESP32 church drain monitor
    Field firmware (SR04_Characterize), bench harness, and hardware docs.
    Credentials moved out of source into a gitignored secrets.h
    (see secrets.example.h); build artifacts (.pio) and binaries ignored.
2026-07-02 Add pull-based OTA (FW_VERSION + manifest poll + httpUpdate)
    Field firmware now self-updates from a GitHub release:
    - Fetches firmware/ota/manifest.txt (raw.githubusercontent, off main);
    flashes via HTTPUpdate only when manifest version > FW_VERSION.
    - Checks ~1 min after boot then every 6h, gated on WiFi up AND water low
    (lastLevelIn < WARN_IN) so an update reboot never silences an alarm.
    - Reports running fw version as an InfluxDB field for Grafana visibility.
    - Pin default.csv partitions (dual app partitions required for OTA).
    - firmware/ota/README.md documents the publish/rollback process.
    Compiles clean; flash 72.3% of the 1.31MB app partition (fits for OTA).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
    [StJoesDrainMonitor.ino]
2026-07-02 Add network-independent post-update self-check
    Decide binary health LOCALLY instead of inferring it from Grafana silence:
    - Classify each boot via esp_reset_reason() + an NVS (Preferences) crash
    counter that survives power loss; log clean / CRASH / SUSPECT-BUILD.
    - Brownout is flagged as a POWER fault and does NOT count toward the
    suspect threshold (a flaky supply must not masquerade as a bad build).
    - Mark firmware good after 60s stable run; surface reset reason as the
    'rst' telemetry field so Grafana can annotate reboots.
    Still no auto-revert (Arduino-ESP32 bootloader lacks app-rollback); this
    surfaces a bad build, USB reflash still needed to recover one. Compiles clean.
    Co-Authore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
    [StJoesDrainMonitor.ino]
2026-07-02 Release firmware v2 (OTA pull test)
    Bump FW_VERSION 1->2 and point manifest at the fw-v2 release. No functional
    change — validates the OTA download+flash+reboot+self-check path end to end.
    [StJoesDrainMonitor.ino]
2026-07-23 Re-arm NTP on WiFi reconnect; report SSID in telemetry (fw v3)
    Telemetry is gated on a valid clock (readings are only buffered once
    time(nullptr) looks real), but NTP was attempted exactly once, in setup().
    A device that powers up out of WiFi range therefore never synced, and the
    gate stayed shut even after WiFi later came back -- ESP-IDF's background
    SNTP client only retries about hourly, so reconnecting produced no data
    for up to an hour. Found at the church: the guest SSID turned out to be
    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
2026-07-28 Store-and-forward telemetry + on-device history download (fw v5)
    The unit lives at a site with no dependable WiFi, so it has to assume it is
    usually offline. It didn't: readings were only buffered once NTP had produced a
    real clock, which never happens on a box that powers up out of range. A visit
    with a phone hotspot therefore yielded only live data — there was never a
    backlog to send.
    Timestamps
    - Readings are stamped with uptime and buffered unconditionally. The epoch
    anchor is learned once (bootEpoch = now - uptime) and the backlog is
    back-dated on the way out.
    - The flash log outlives reboots but uptime restarts at zero on each one, so
    every record carries the boot session that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
    [StJoesDrainMonitor.ino]
2026-09-13 Add field log with recovered v5 install record; consolidate project home
    v5 was installed over the air on 2026-08-27 and validated on 2026-08-30, but the
    record lived only in Claude session history on a second laptop. field-log.md now
    carries the visit outcomes in the repo, and CLAUDE.md tells future sessions to
    keep it current, so a laptop switch no longer loses the trail.
    Also folded in while moving the project to Sparks Analytics/Projects:
    - experiments/ultrasonic-original-2025: the July 2025 first sketch, archived
    - hardware/3d-models: copies of the float, tube liner and sensor cap prints
    - checklist marked done; README layout table updated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
    [Dist Sensor Cap.3mf, Drain Float.3mf, Drain Tube Liner.3mf]
2026-09-13 Don't skip this boot's pre-NTP backlog when flushing on a previous anchor (fw v6)
    After a reboot, flushChunk() proceeds as soon as WiFi is up because the previous
    session's anchor is in NVS. That correctly dates the old session's records, but the
    current session's records resolve to 0 until NTP lands a few seconds later, were
    counted "undatable", and the cursor was advanced past them for good. Twelve days of
    readings went missing that way between 2026-09-01 and 2026-09-13.
    The log is chronological, so this boot's records are always the tail of a chunk:
    while g_bootEpoch is 0, deliver everything older and stop at the first record from
    this session. If the chunk starts with our own records, r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
    [StJoesDrainMonitor.ino]
2026-10-23 fw v8: widen empty-drain deadband; point OTA manifest at fw-v8
    After the 2026-10-22 remount the dry resting distance settled at raw
    22.7-23.1 cm, which computes to 1.25-1.42 in and straddles the old 1.4 in
    clamp, so an empty drain flickered between 0.00 and 1.42. Raise
    DEADBAND_IN to 1.8 in so the idle series is flat.
    WARN/WARN2/ALARM are unchanged, so overflow detection is untouched.
    Also records the 10-22 site visit: the RE315 bridge is up and the unit is
    continuously online, the suspected sensor failure was the probe reading the
    table it was lying on, and brief spikes over 5 in turn out to be routine
    sink use rather than incidents.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
2026-10-23 fw v9: alarm dwell, hourly OTA checks, fast retry after a failed check
    Alarm dwell: the level must stay at/above ALARM_IN for 45 s before the
    latching beep-until-ack starts. A sink-overflow test peaked at 5.40" and
    cleared in ~10 s, and the three events logged in the preceding fortnight
    have the same ~9 s shape, so routine kitchen water use was latching the
    95 dB alarm until somebody silenced it by hand. Persistence, not peak, is
    what separates normal use from a backup. The LED bar, red lamp and
    escalating chirps stay instantaneous and the buzzer holds at the WARN2
    fast chirp during the dwell, so a real event still escalates from the
    first second. Only a drop below ALARM_CLEAR_IN cancels the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
2026-10-23 fw v10: revert the v9 alarm dwell — alarm latency must be zero
    v9 added a 45 s dwell before the latching alarm, reasoned from telemetry
    alone: sink discharges clear in ~10 s, so filtering on persistence rather
    than peak looked like the way to stop routine kitchen use latching the
    95 dB buzzer.
    That missed the physical constraint. A partially clogged drain can go from
    normal to overflowing in about 20 seconds, so any dwell long enough to
    filter a sink discharge is also long enough for the floor to be wet before
    the buzzer sounds. The box exists to give the person at the sink the most
    warning possible, so the alarm fires the instant the level crosses
    ALARM_IN. A false alarm roughly once a f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
2026-10-23 Field log: live overflow test — 11 s WARN-to-ALARM, confirms the v9 dwell would have been silent
2026-10-26 Field log: 4.5 in plateaus since 10-25 are a spurious 16 cm echo, not water
    Pulled every reading since 10-22 via a Grafana viewer token. The raw distance
    flips 22.4 -> 15.6-16.0 cm in a single sample with no transit values, so the
    float never moves; a wall/liner echo is winning the median. Liner was disturbed
    in the 10-22 remount. Inspect ~16 cm below the sensor on the next visit; alert
    rule on hold until fixed.
